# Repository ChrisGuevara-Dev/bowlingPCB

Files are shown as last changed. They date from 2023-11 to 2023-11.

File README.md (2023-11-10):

# Bowling PCB
This project focused on creating a printed circuit board (PCB) for the precise control of a bowling machine, utilizing the KiCAD design platform and the ESP32 microcontroller. The compact and robust design aimed to enhance the accuracy and reliability of ball launches, providing a comprehensive solution compatible with KiCAD standards.

## Schematic
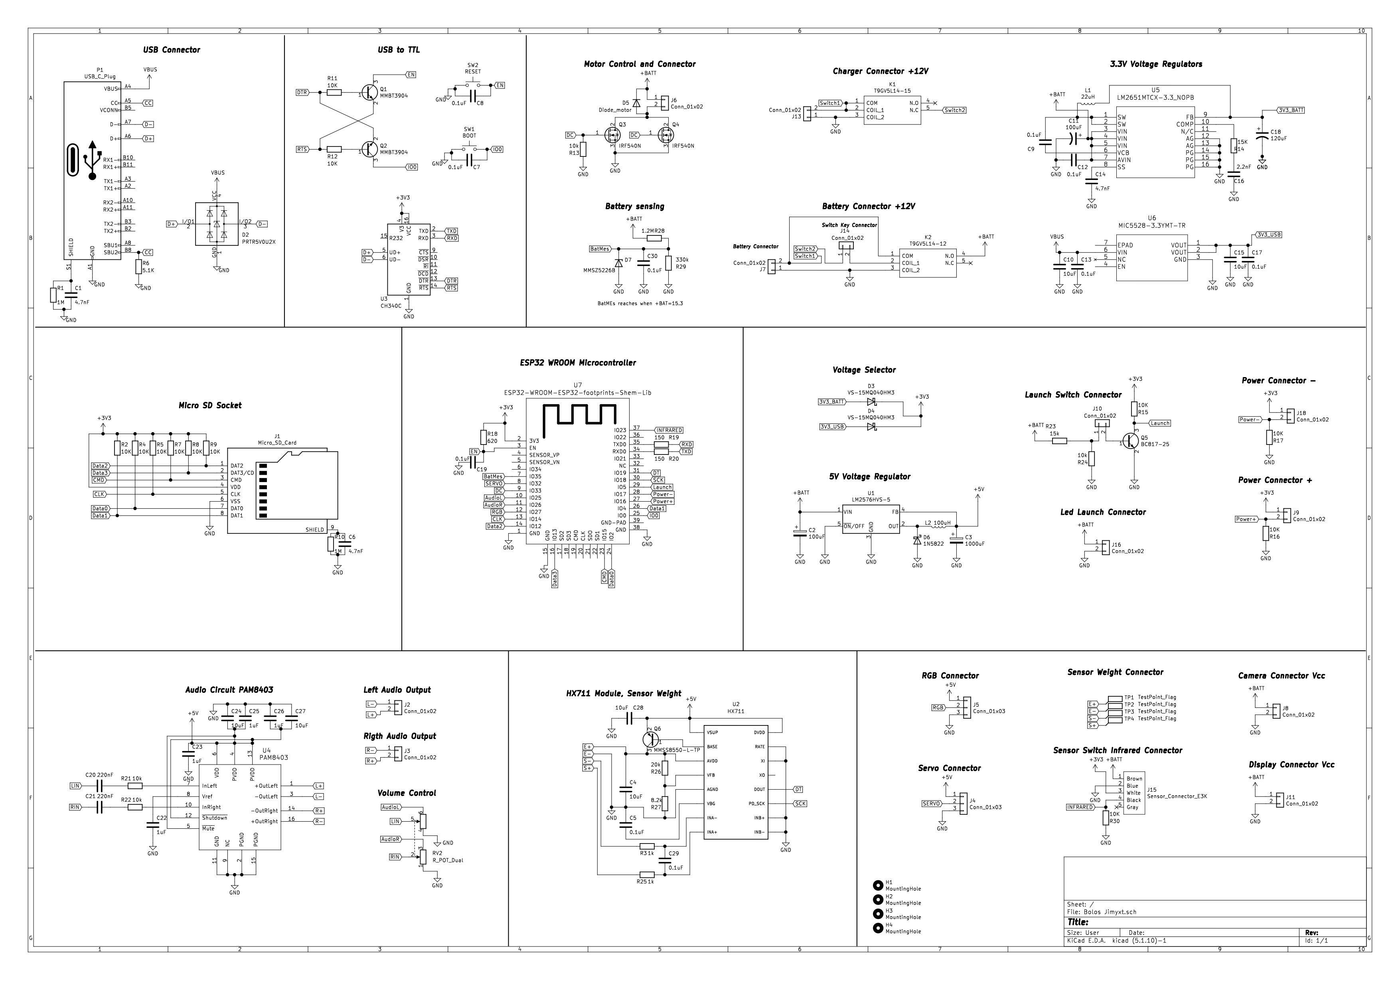
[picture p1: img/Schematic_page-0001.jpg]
Schematic


## 3D Model & Footprint
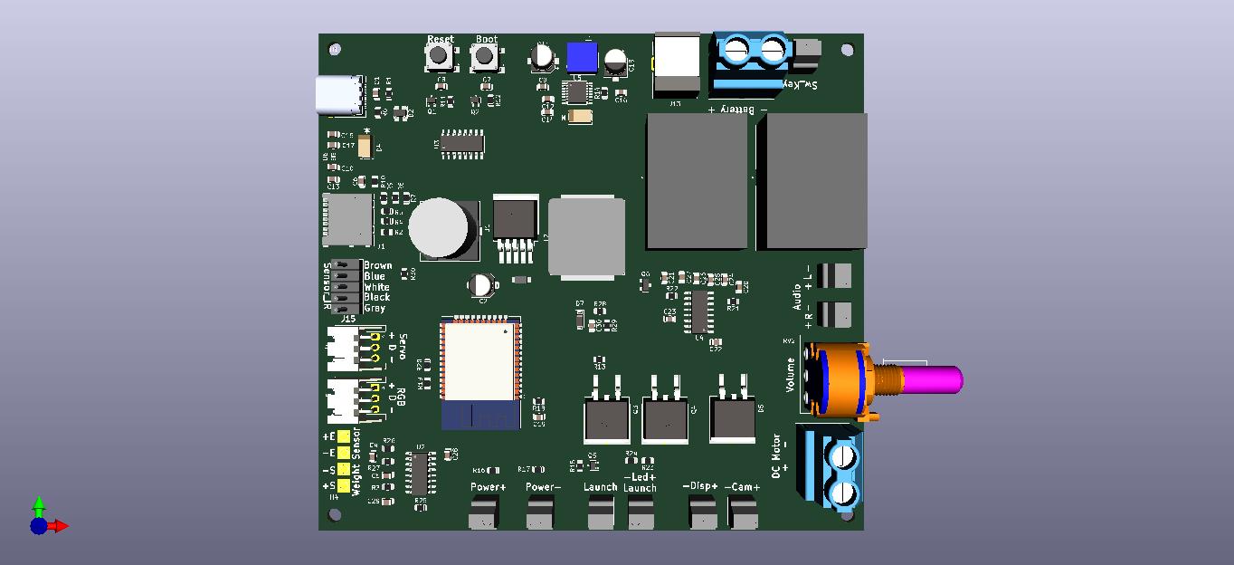
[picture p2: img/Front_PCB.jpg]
3D Model 1

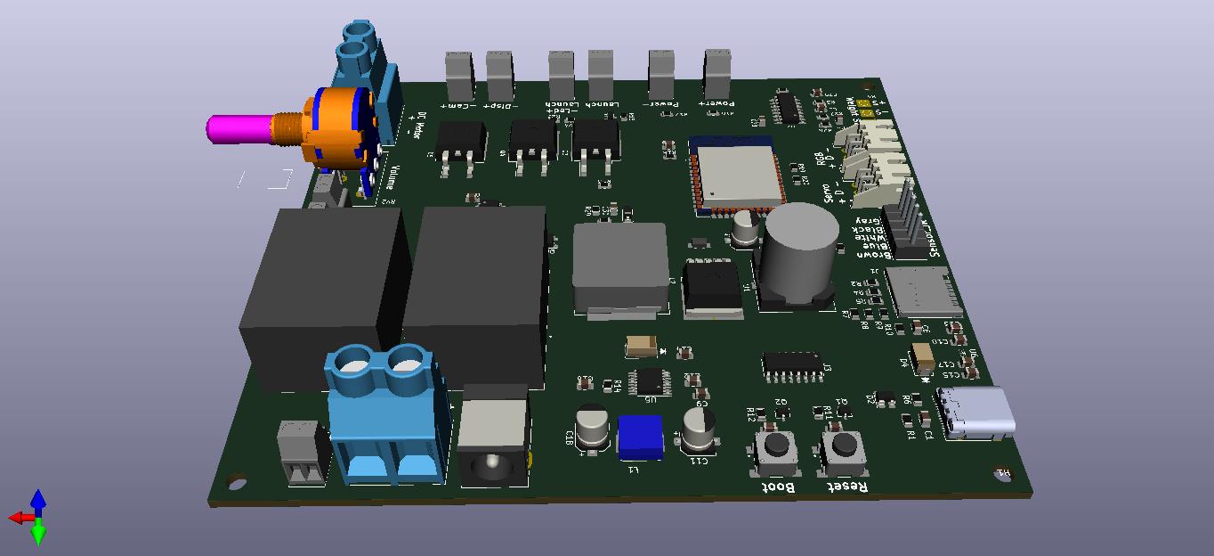
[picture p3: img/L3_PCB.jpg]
3D Model 2

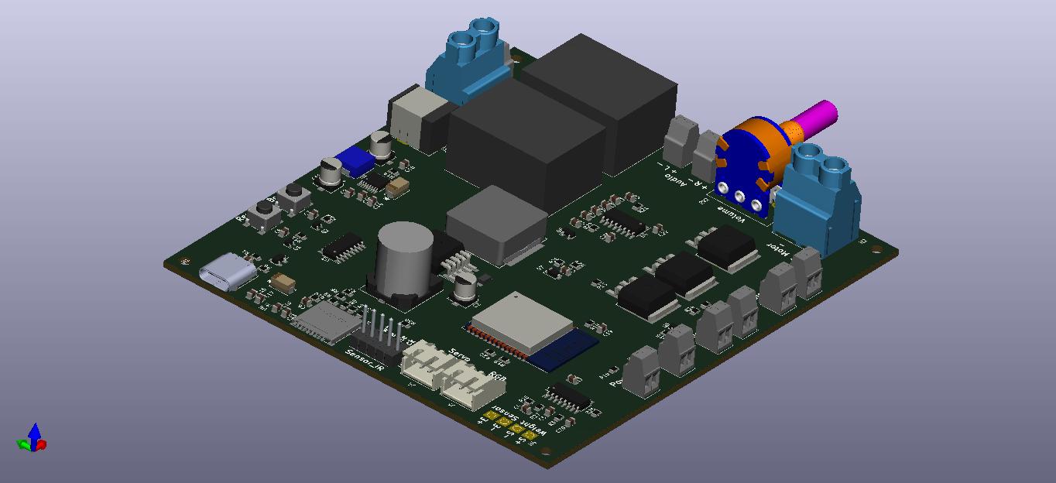
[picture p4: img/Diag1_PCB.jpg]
3D Model 3

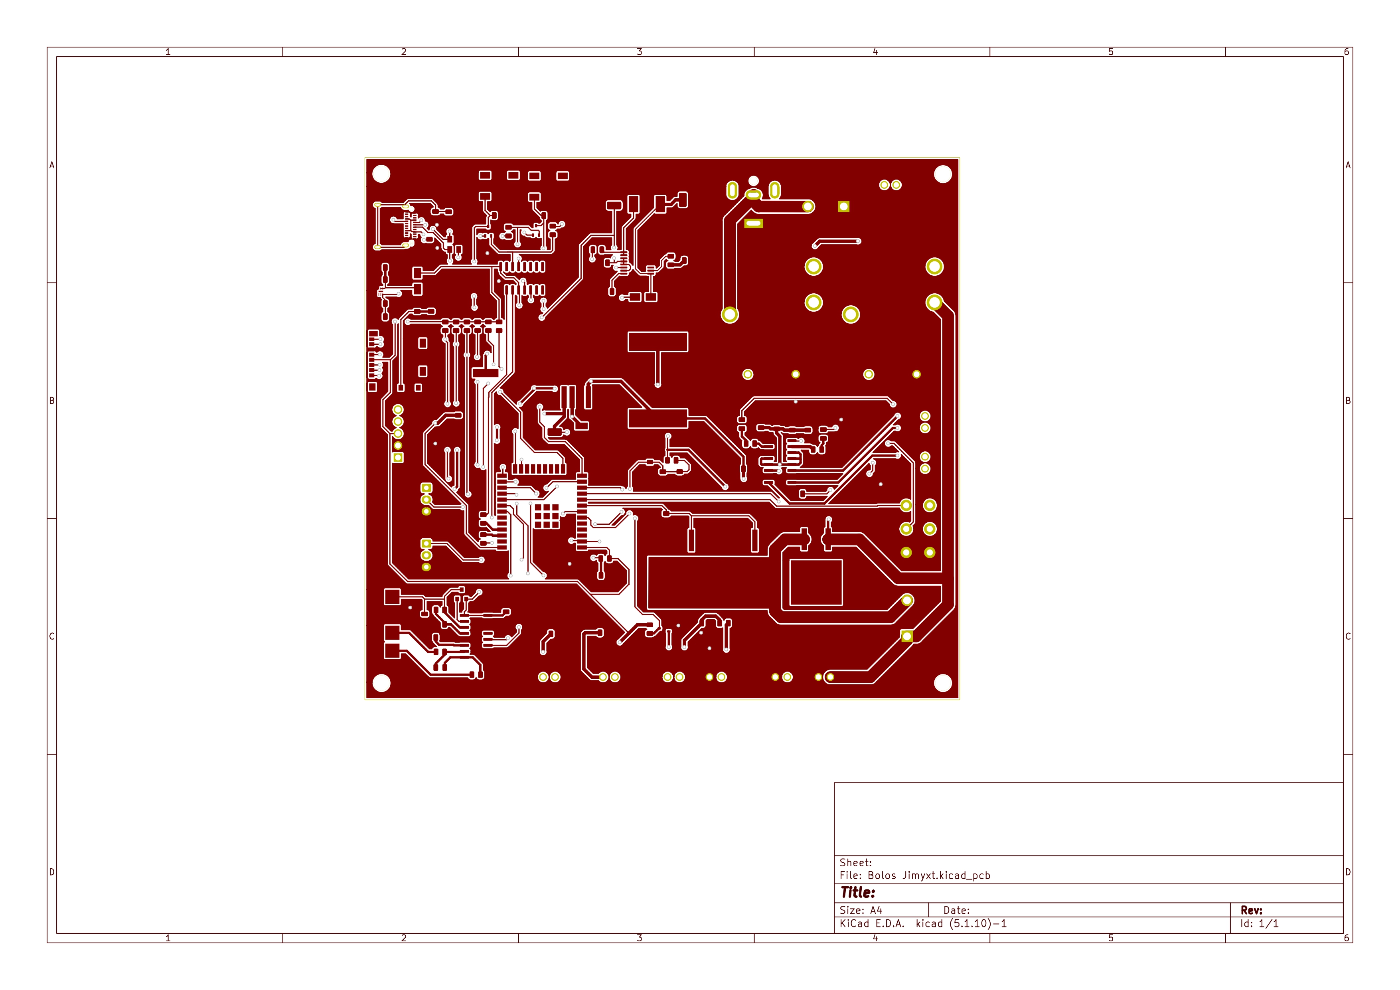
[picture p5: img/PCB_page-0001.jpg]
Footprint


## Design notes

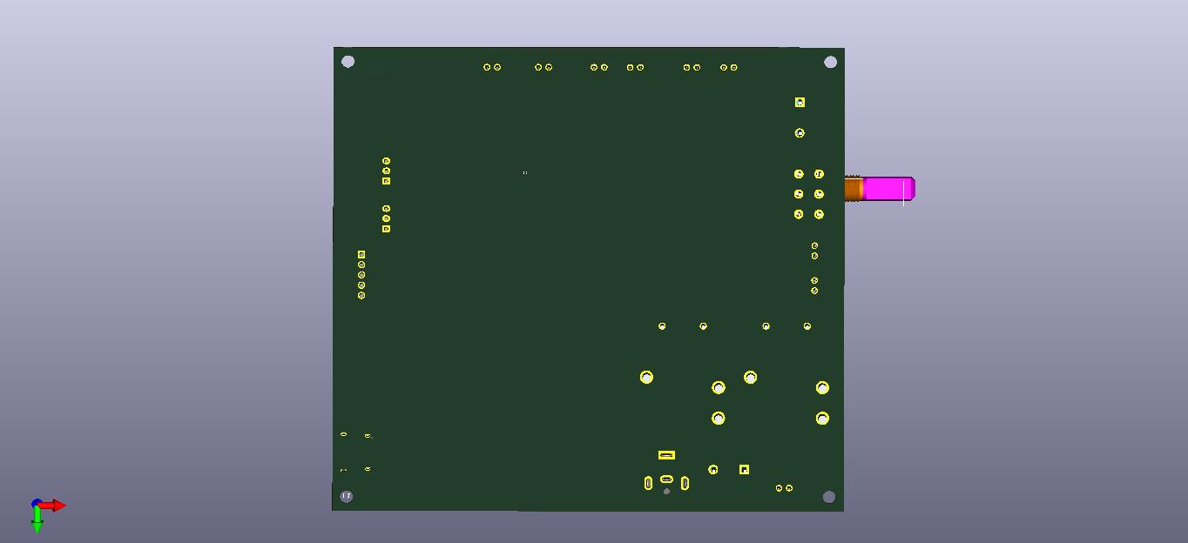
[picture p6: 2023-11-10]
img/Back_PCB.jpg

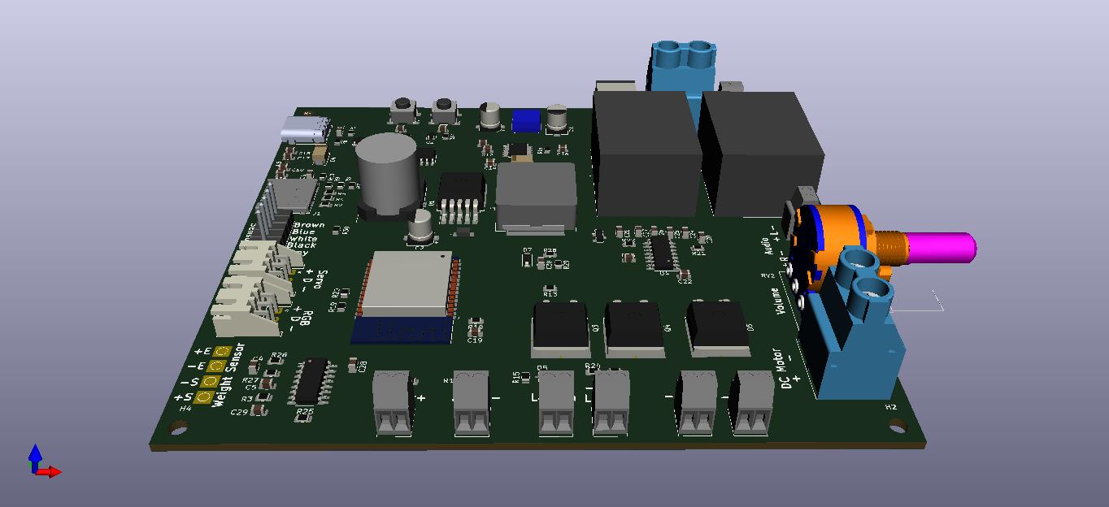
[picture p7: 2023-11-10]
img/L1_PCB.jpg

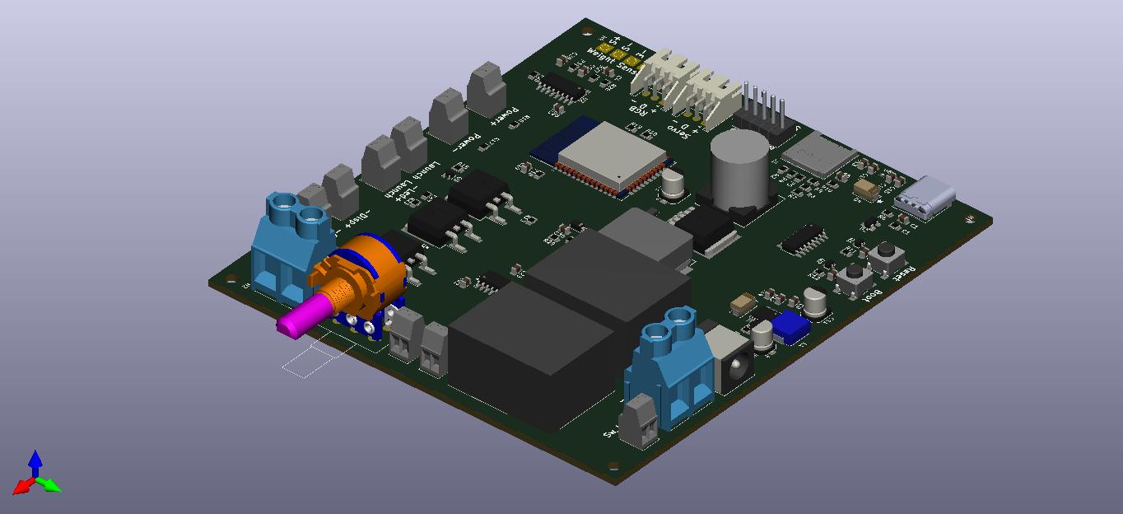
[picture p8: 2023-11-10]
img/Diag3_PCB.jpg

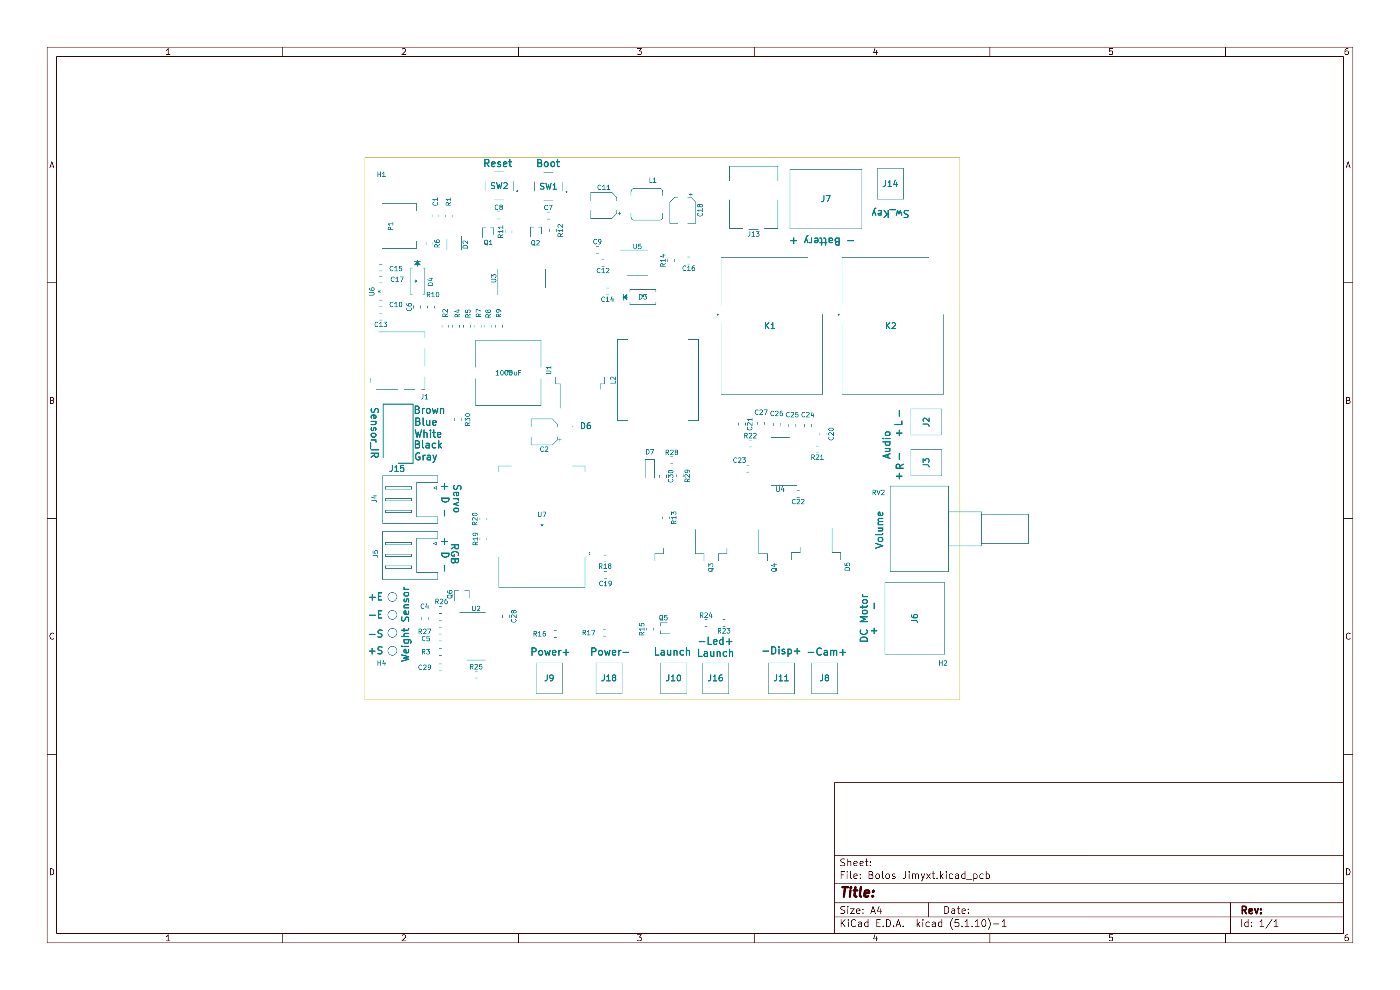
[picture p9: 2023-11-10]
img/PCB_page-0005.jpg

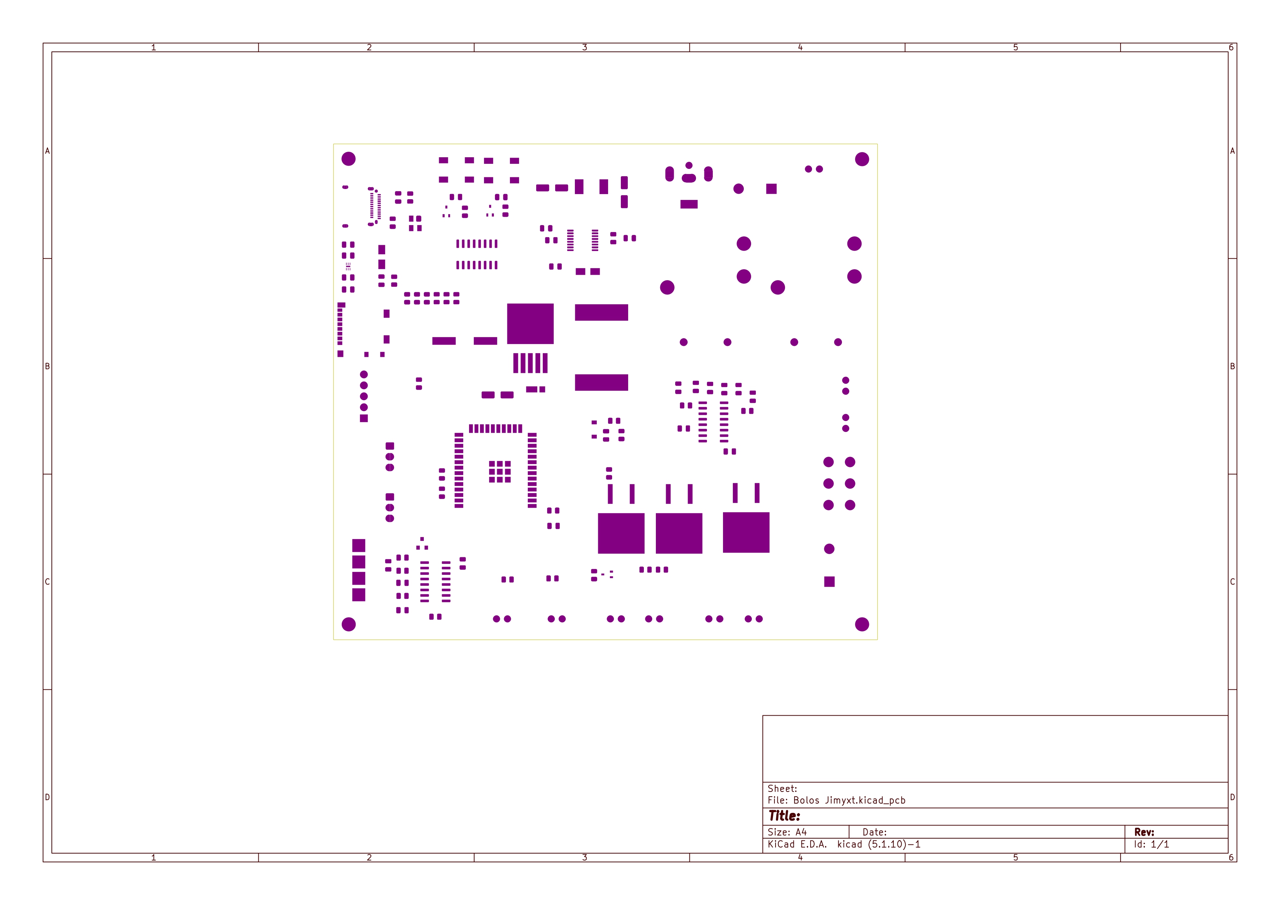
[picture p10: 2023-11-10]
img/PCB_page-0007.jpg

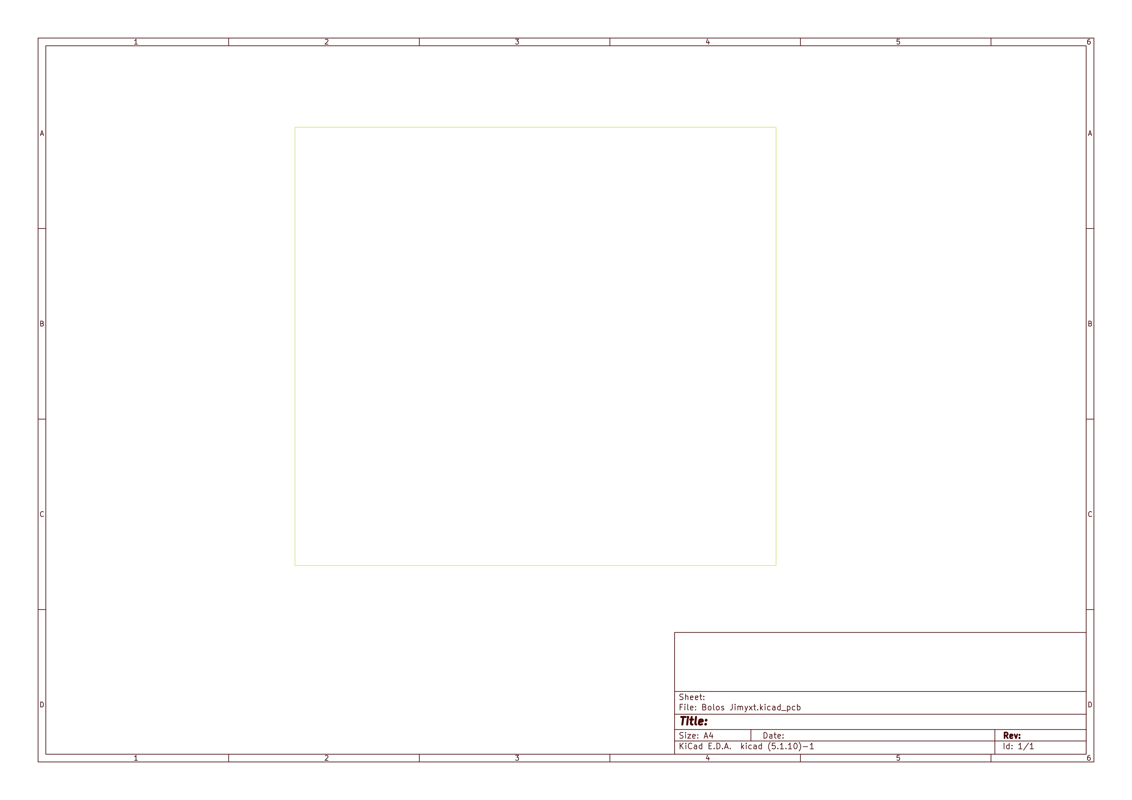
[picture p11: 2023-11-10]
img/PCB_page-0009.jpg

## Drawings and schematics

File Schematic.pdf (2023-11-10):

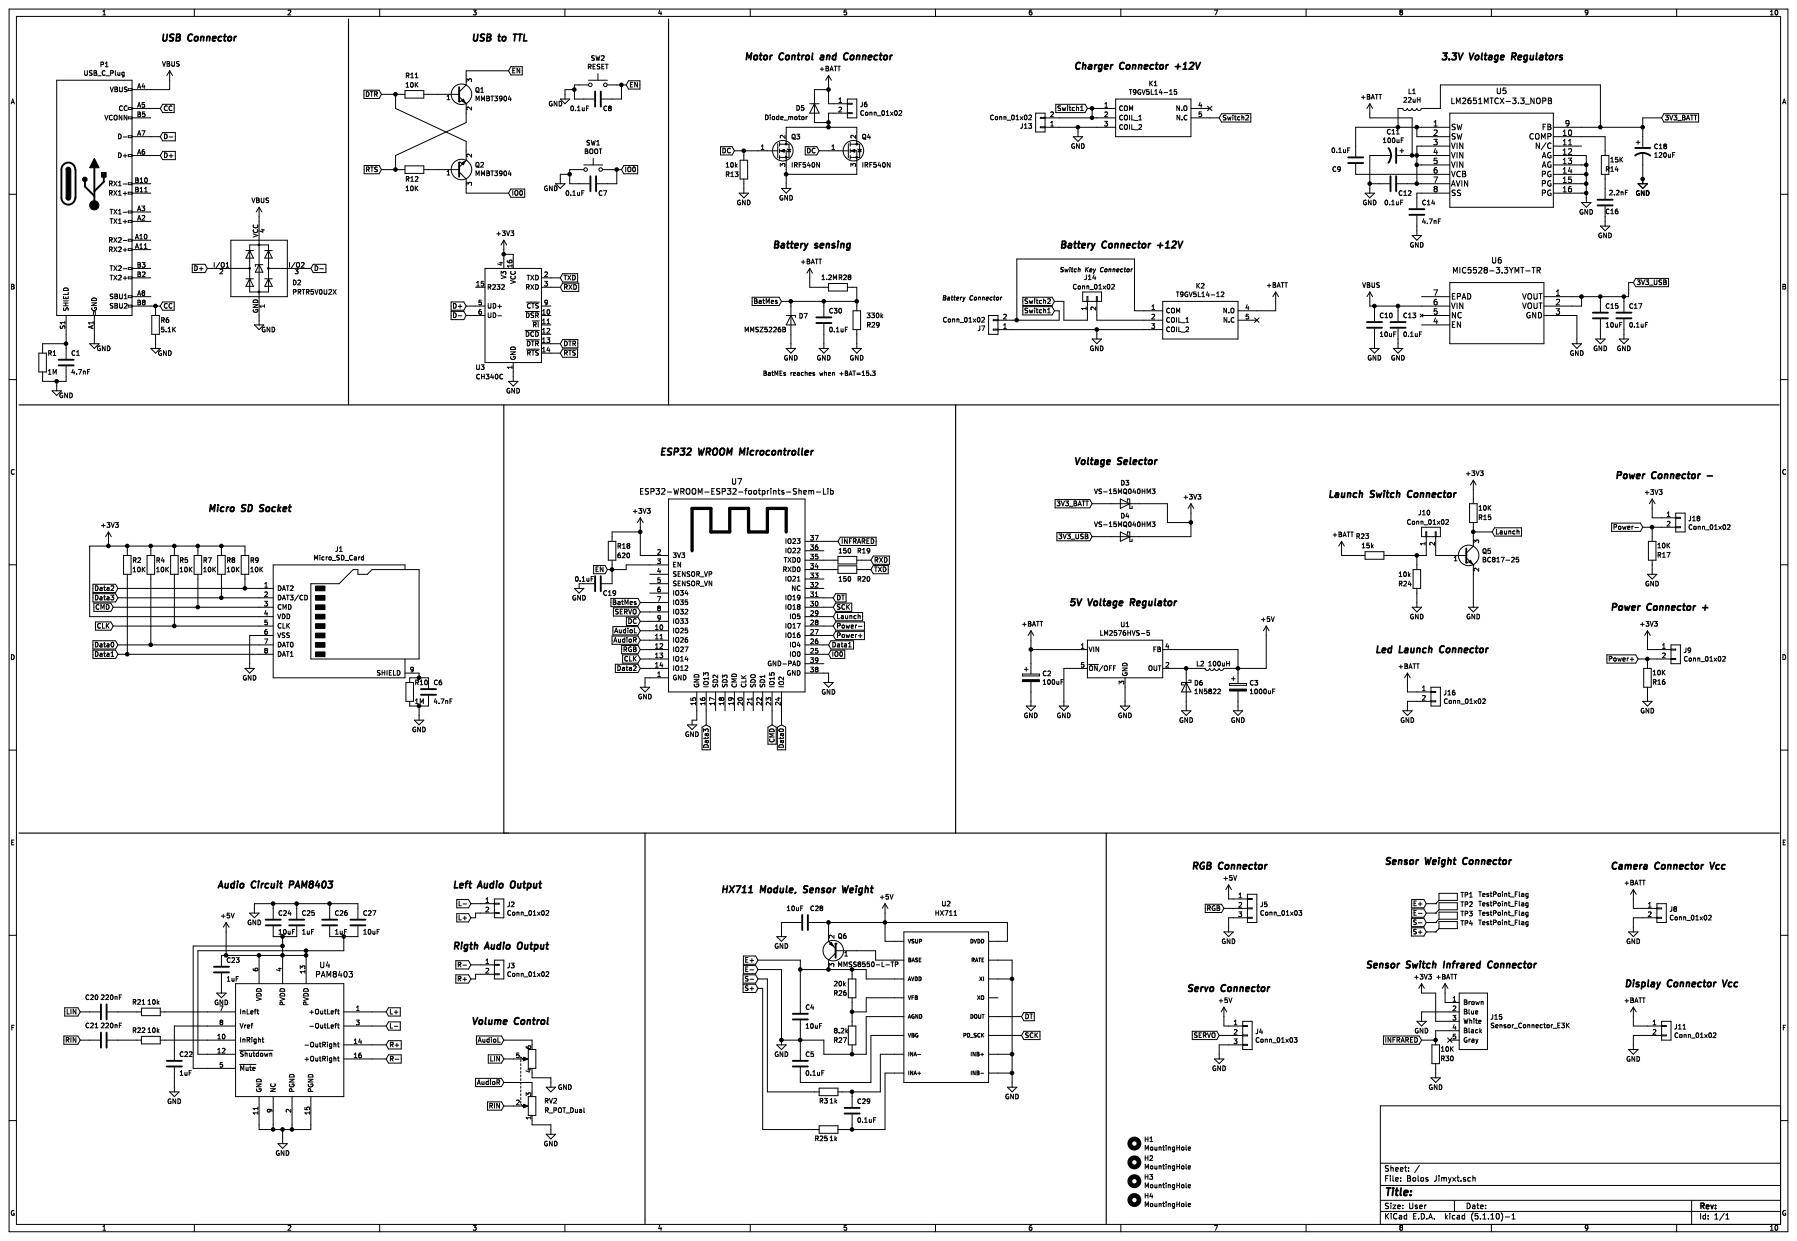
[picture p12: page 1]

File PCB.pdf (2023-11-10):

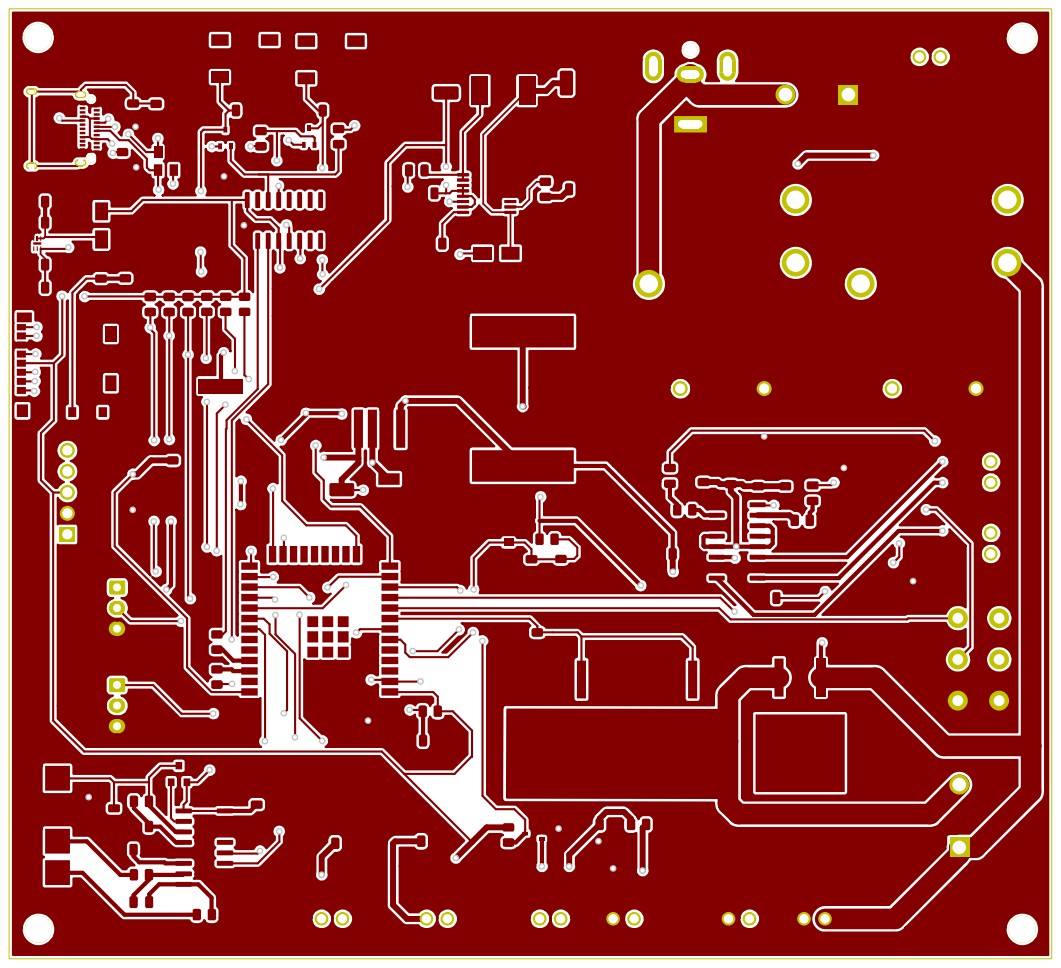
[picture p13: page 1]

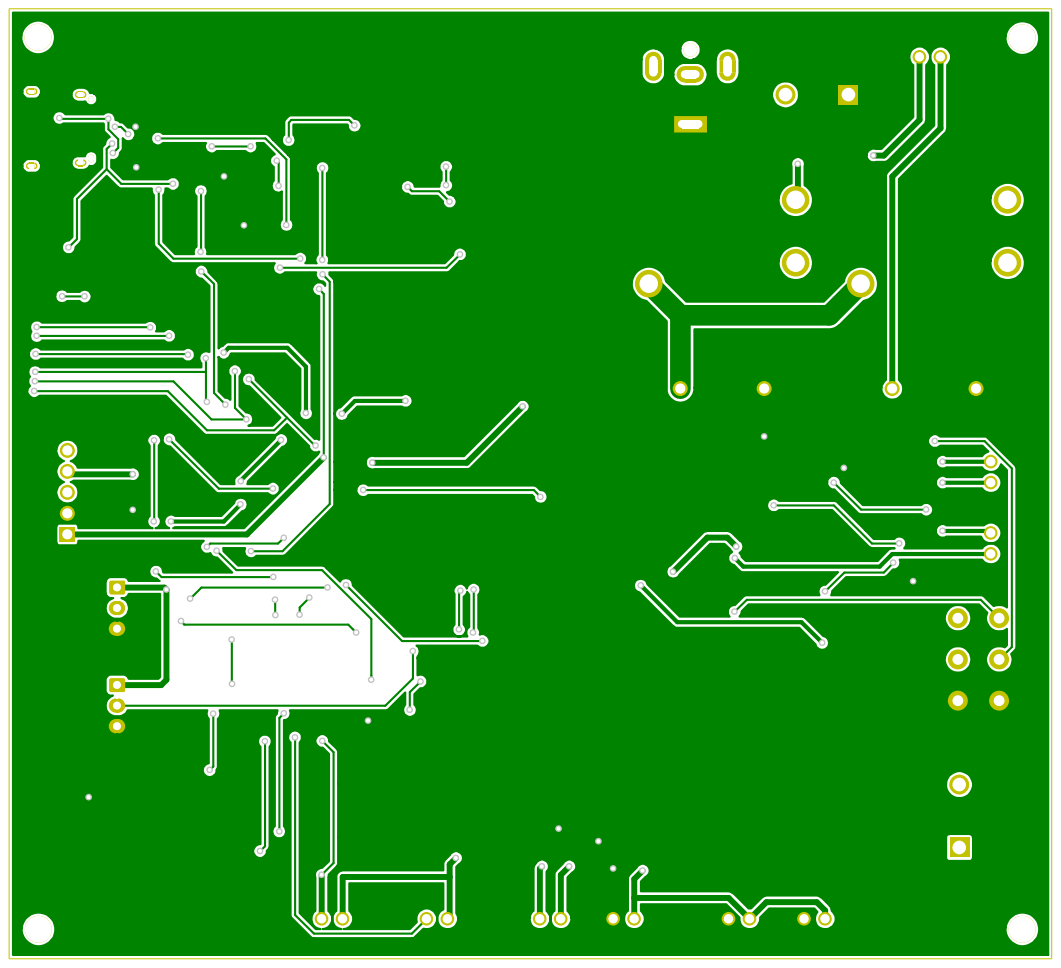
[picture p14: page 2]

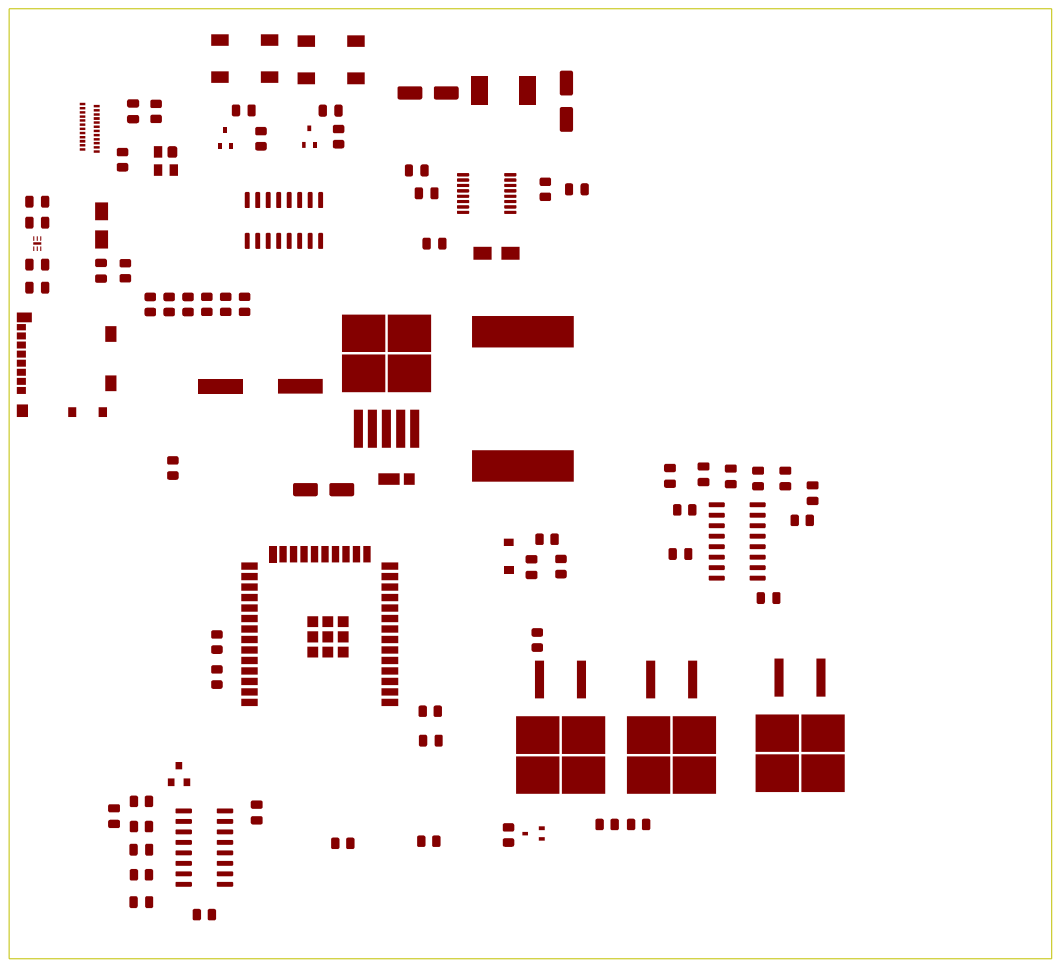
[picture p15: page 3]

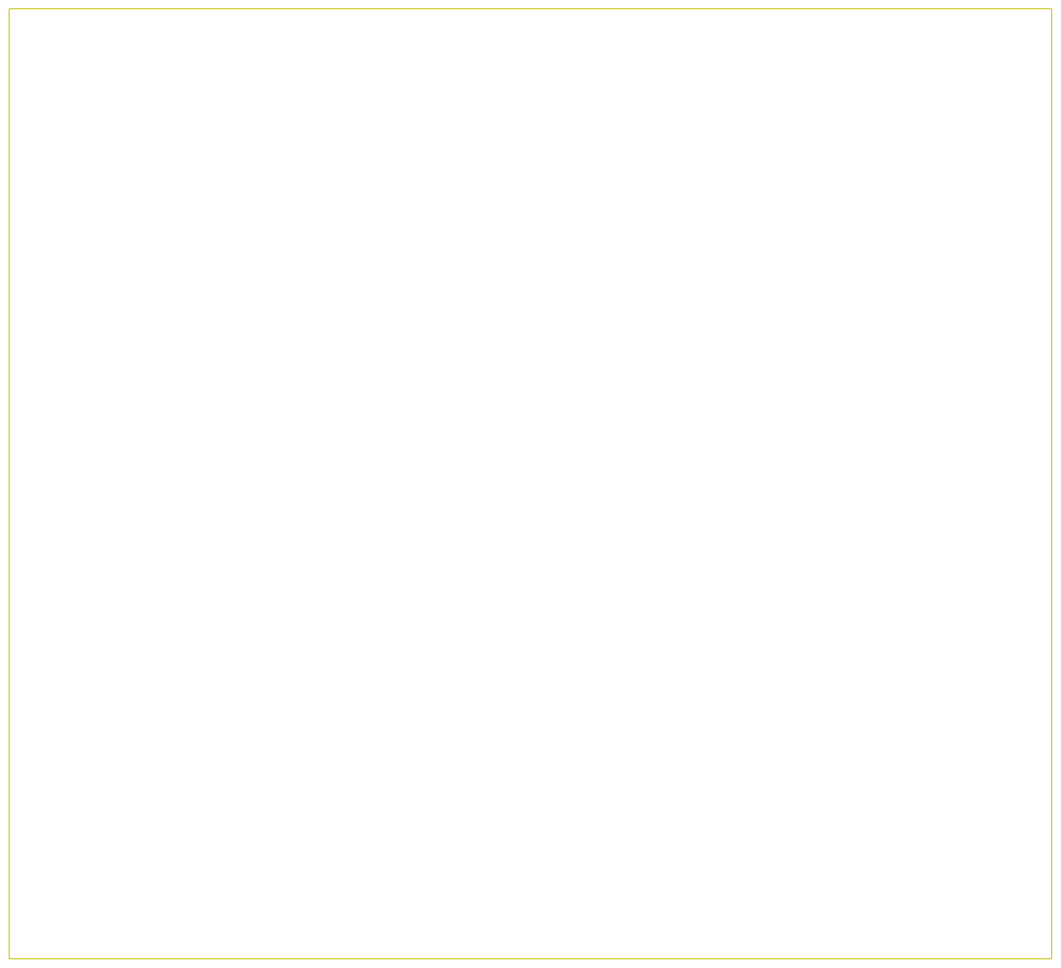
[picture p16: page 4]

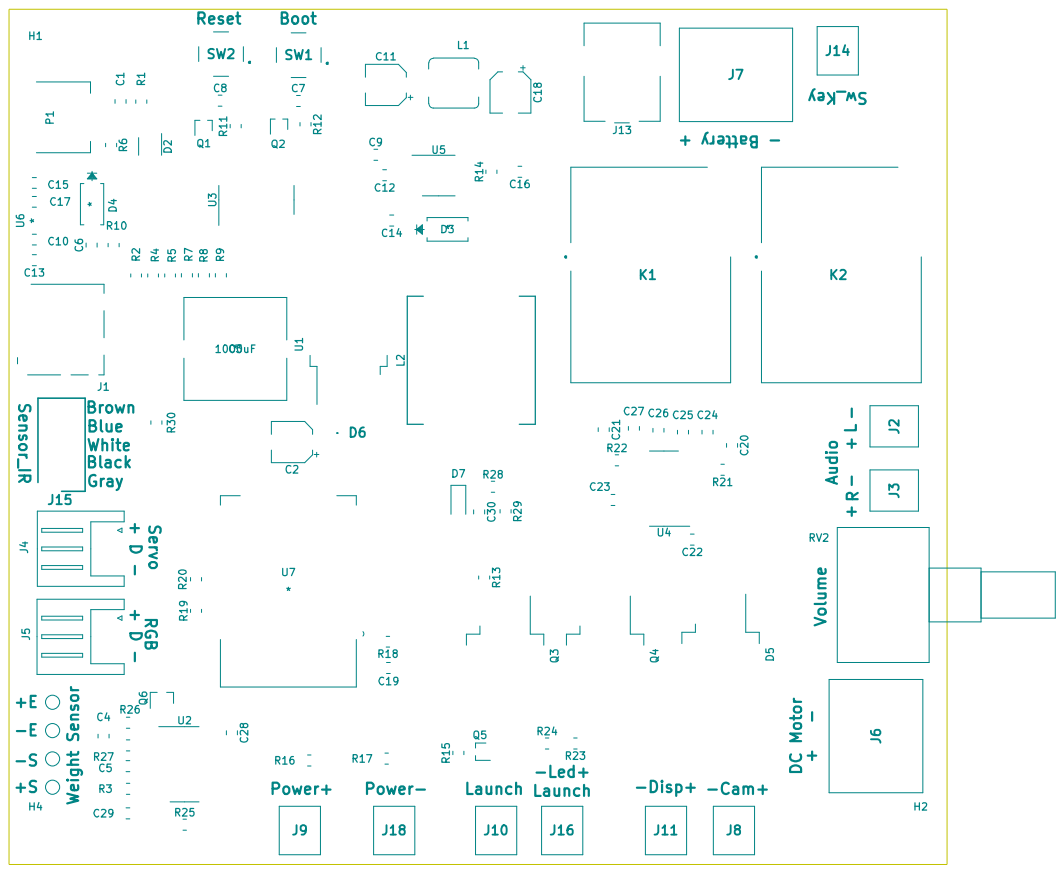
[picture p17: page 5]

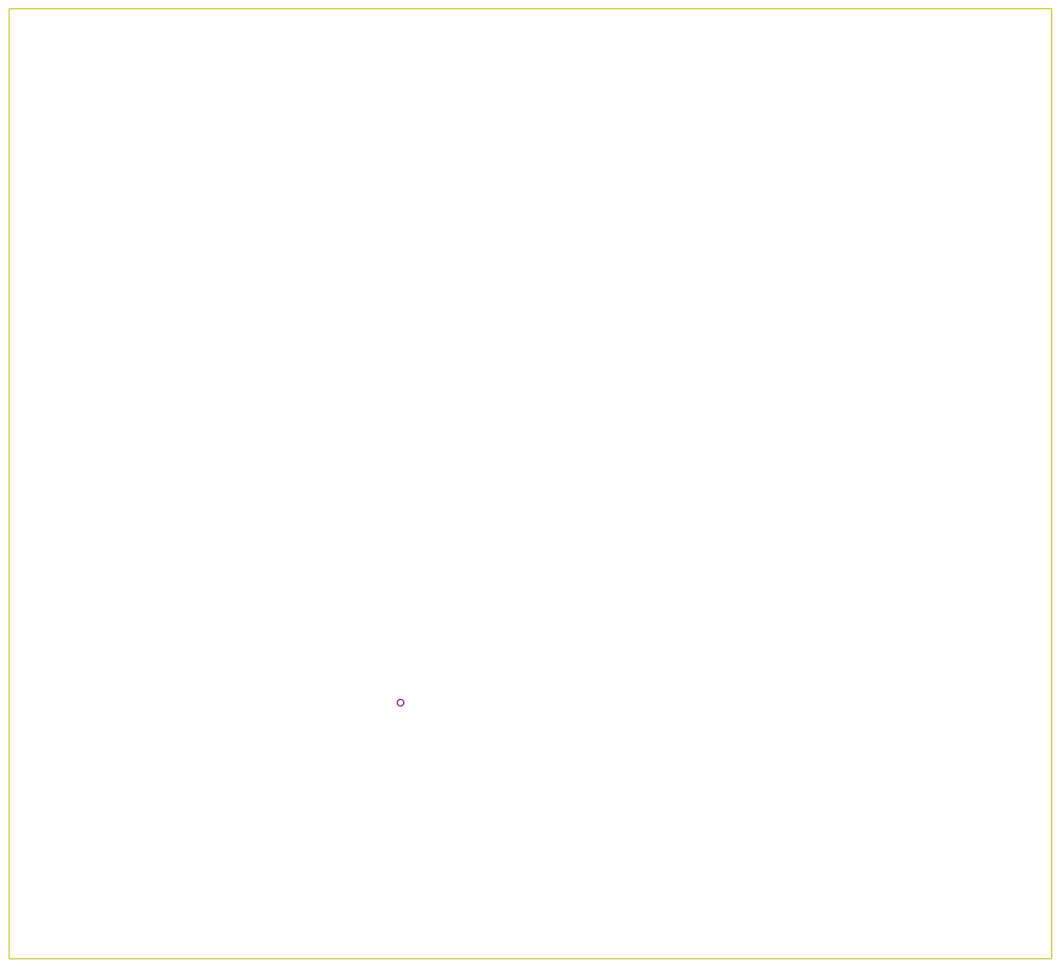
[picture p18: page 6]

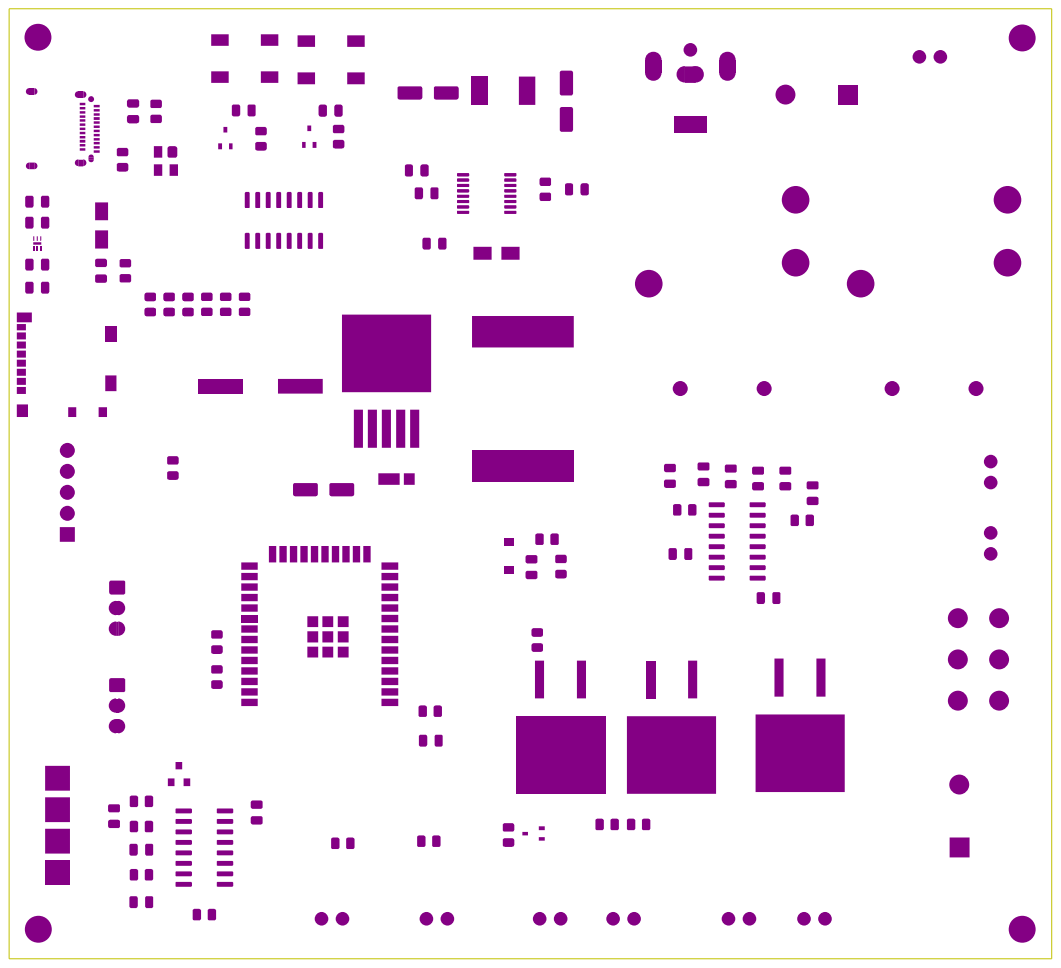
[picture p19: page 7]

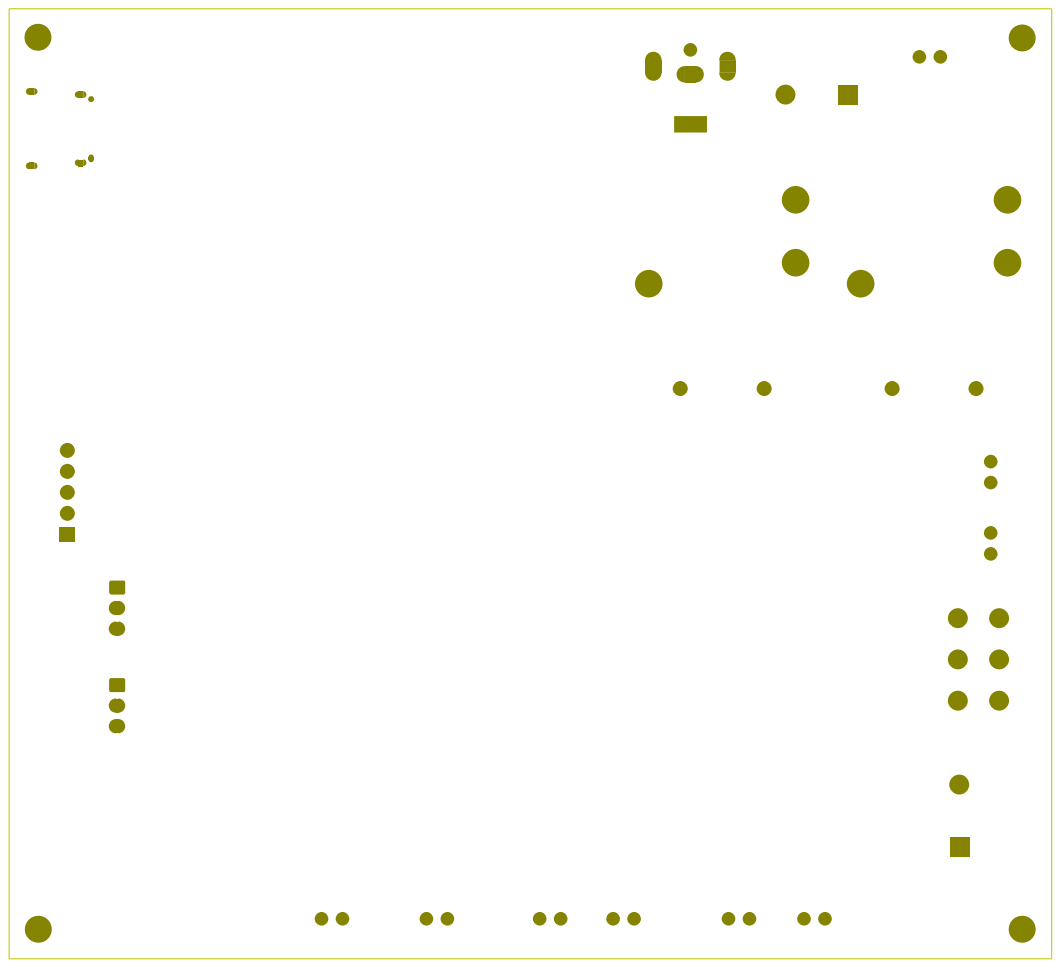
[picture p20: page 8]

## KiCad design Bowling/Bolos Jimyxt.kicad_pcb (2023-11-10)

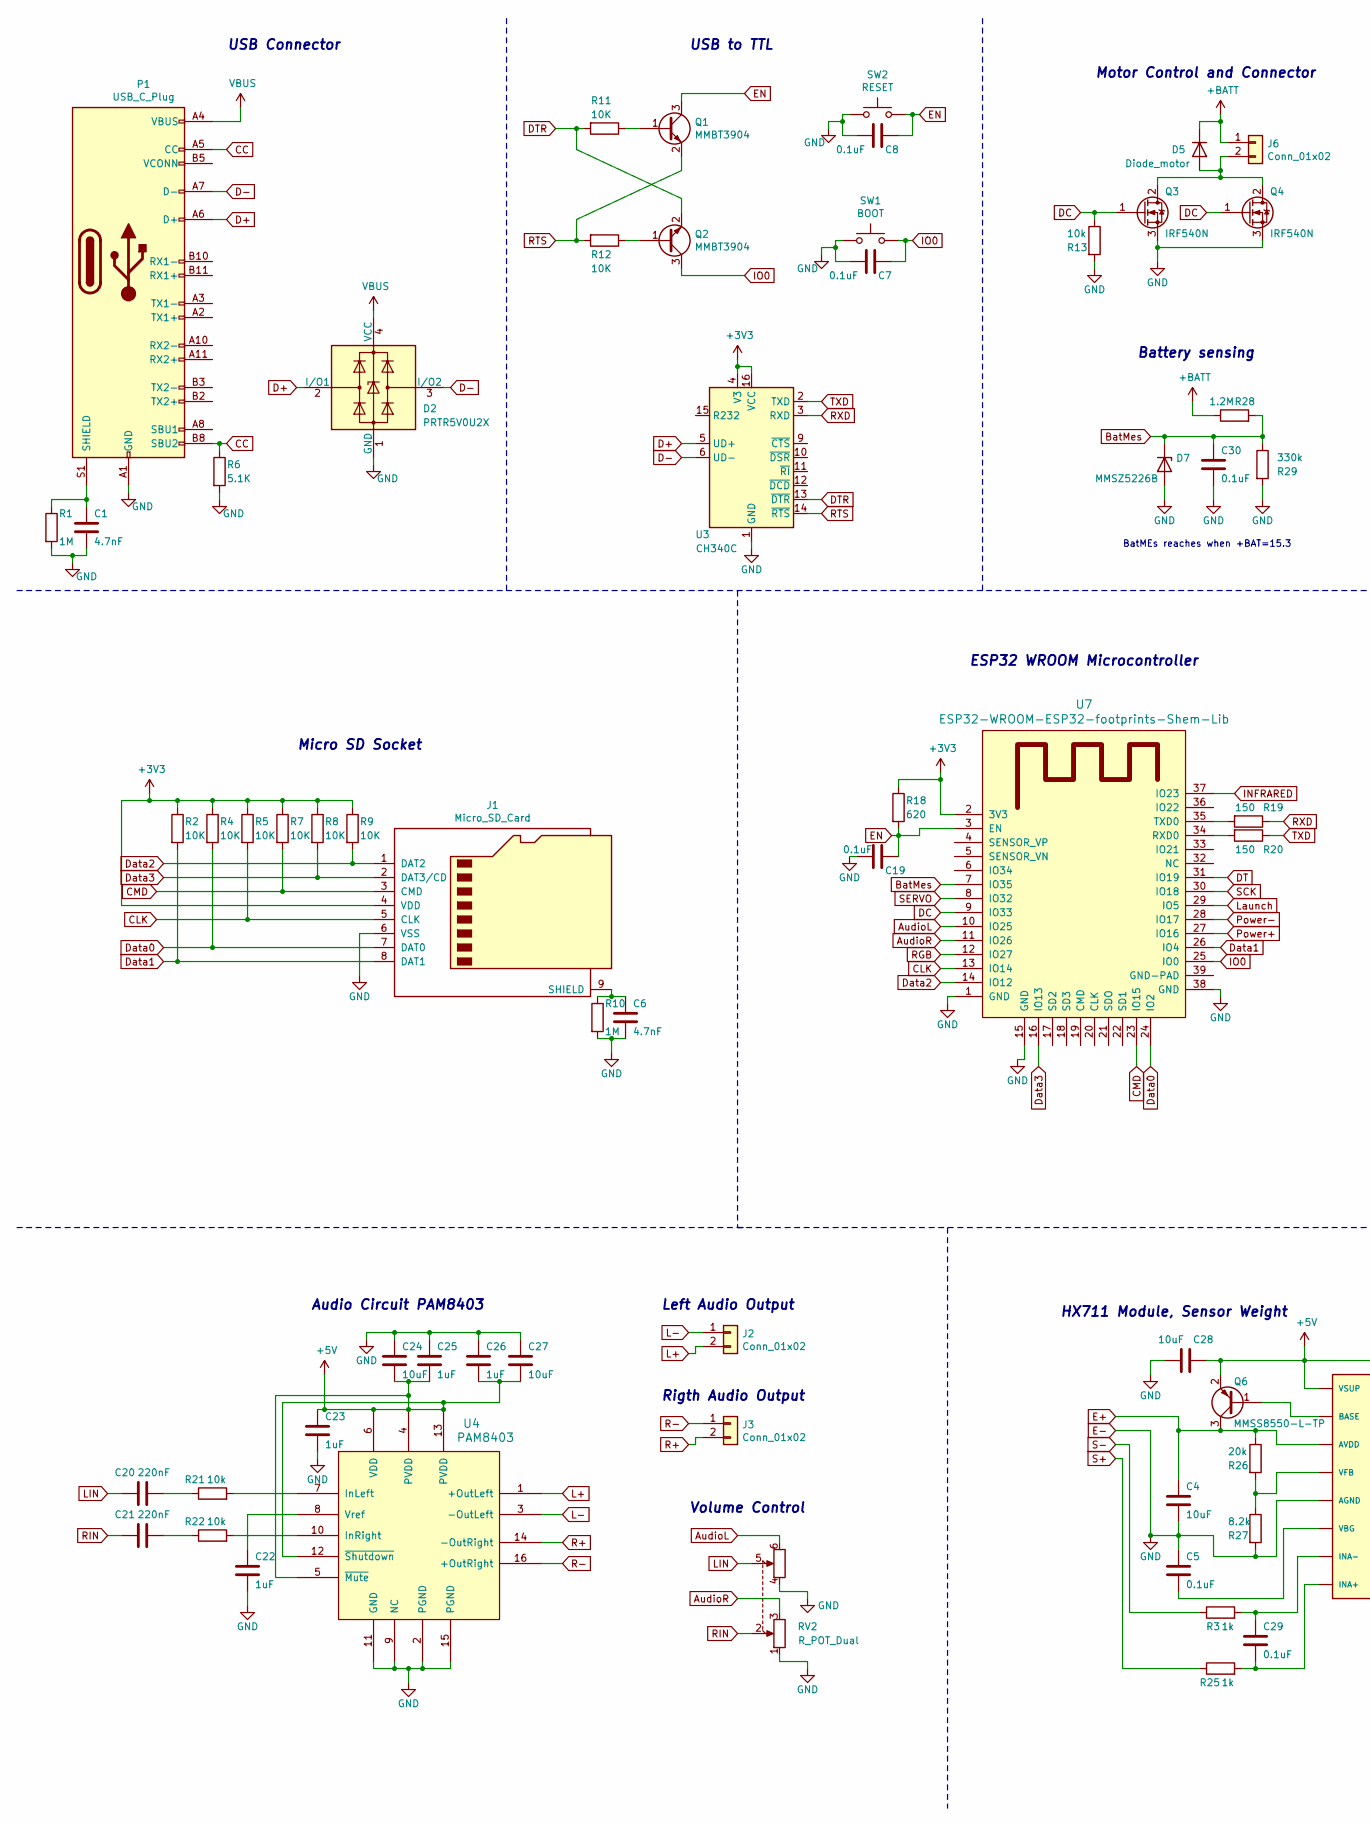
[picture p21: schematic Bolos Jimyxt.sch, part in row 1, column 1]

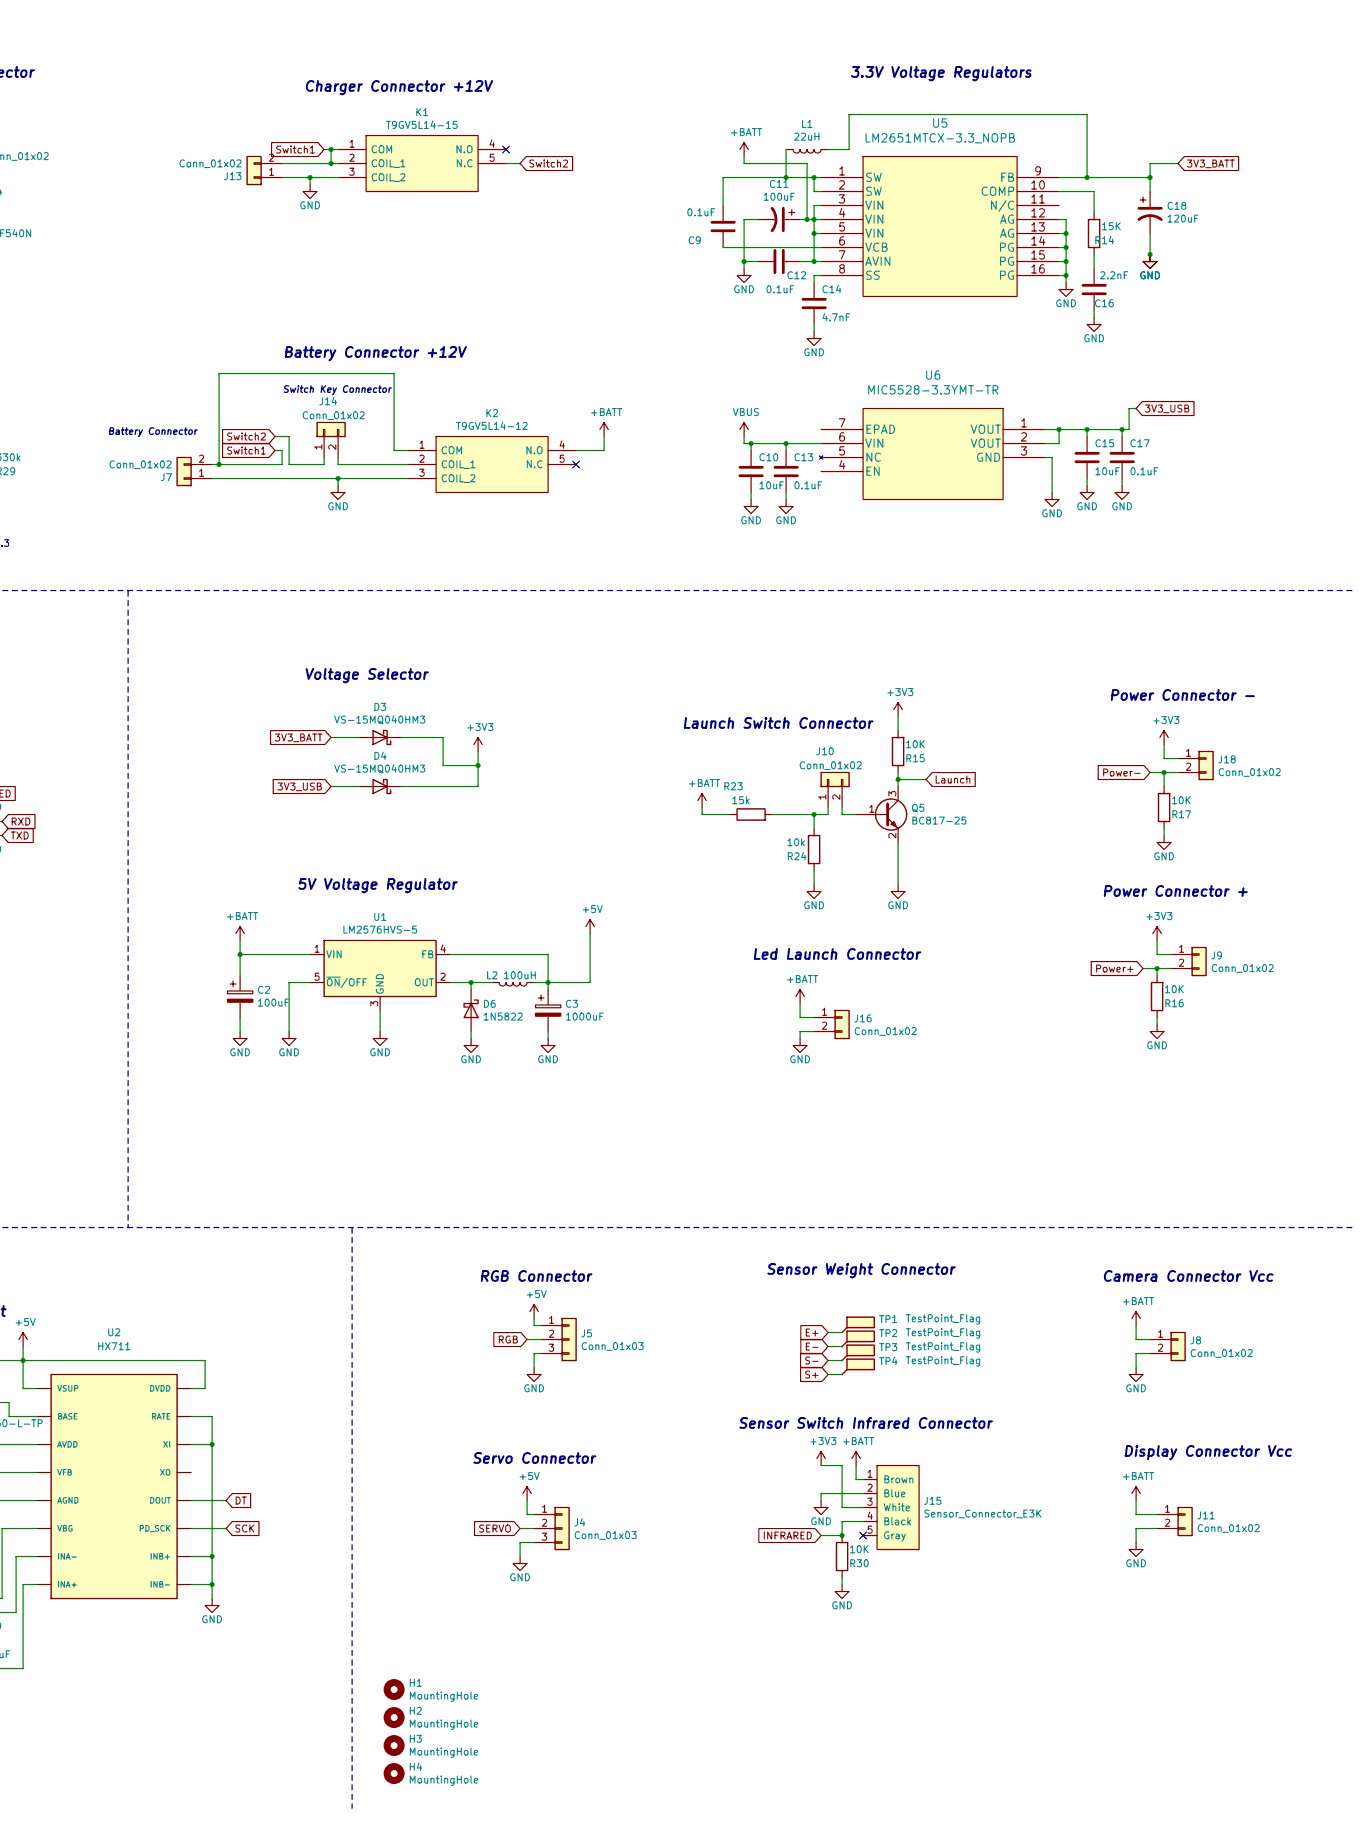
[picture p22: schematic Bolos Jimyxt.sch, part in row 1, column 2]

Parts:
C1, C6, C14: 4.7nF; C_0805_2012Metric; MFG PN C0805C472J3GEC7210
C2, C11: 100uF; CP_Elec_5x5.8; MFG PN EEE-FK1C101SR
C3: 1000uF; UUG1A102MNQ1MS; MFG PN UUG1A102MNQ1MS
C4, C10, C15, C24, C27, C28: 10uF; C_0805_2012Metric; MFG PN C2012X5R1E106M125AB
C5, C7, C8, C9, C12, C13, C17, C19, C29, C30: 0.1uF; C_0805_2012Metric; MFG PN C0805C104J3RECAUTO7210
C16: 2.2nF; C_0805_2012Metric; MFG PN C0805C222K3GECTU
C18: 120uF; CP_Elec_5x5.8; MFG PN EEE-FK1A121SR
C20, C21: 220nF; C_0805_2012Metric; MFG PN C0805C224J3RACTU
C22, C23, C25, C26: 1uF; C_0805_2012Metric; MFG PN C0805C105M3REC7210
D2: PRTR5V0U2X; SOT-143; MFG PN PRTR5V0U2X,215
D3, D4: VS-15MQ040HM3; VS-15MQ040NPBF; MFG PN VS-15MQ040HM3/5AT
D5: Diode_motor; TO-263-2; MFG PN PSDB3060S1_T0_00001
D6: 1N5822; SS3040HE_R1_00001; MFG PN SS3040HE_R1_00001
D7: MMSZ5226B; D_SOD-123; MFG PN MMSZ5226B_R1_00001
H1, H2, H3, H4: MountingHole; MountingHole_3.2mm_M3; MFG PN DNP
J1: Micro_SD_Card; microSD_HC_Molex_104031-0811; MFG PN 104031-0811
J2, J3, J8, J9, J10, J11, J14, J16, J18: Conn_01x02; 397730002; MFG PN 39773-0002
J4, J5: Conn_01x03; JST_XH_S3B-XH-A_1x03_P2.50mm_Horizontal; MFG PN S3B-XH-A(LF)(SN)
J6, J7: Conn_01x02; TB00576202BE; MFG PN TB005-762-02BE
J13: Conn_01x02; BarrelJack_CUI_PJ-063AH_Horizontal; MFG PN PJ-063AH
J15: Sensor_Connector_E3K; 171856-0105; MFG PN 171856-0105
K1: T9GV5L14-15; T9GV5L145; Manufacturer_Part_Number T9GV5L14-5; Mouser Part Number 655-T9GV5L14-5
K2: T9GV5L14-12; T9GV5L145; Manufacturer_Part_Number T9GV5L14-5; Mouser Part Number 655-T9GV5L14-5
L1: 22uH; L_Sumida_CDMC6D28_7.25x6.5mm; MFG PN ASPI-0630LR-220M-T15
L2: 100uH; L_Vishay_IHLP-6767; MFG PN IHLP6767GZER101M11
P1: USB_C_Plug; USB_C_Receptacle_Amphenol_12401610E4-2A; MFG PN 12401610E4#2A
Q1, Q2: MMBT3904; SOT-323_SC-70; MFG PN MMBT3904W_R1_00001
Q3, Q4: IRF540N; TO-263-2; MFG PN IRF540SPBF
Q5: BC817-25; SOT-323_SC-70; MFG PN BC817-25_R1_00001
Q6: MMSS8550-L-TP; SOT-23; MFG PN MMSS8550-L-TP
R1, R10: 1M; R_0805_2012Metric; MFG PN CMP0805-FX-1004ELF
R2, R4, R5, R7, R8, R9, R11, R12, R15, R16, R17, R30: 10K; R_0805_2012Metric; MFG PN ERJ-UP6J103V
R3, R25: 1k; R_0805_2012Metric; MFG PN ERJ-P06F1001V
R6: 5.1K; R_0805_2012Metric; MFG PN ERJ-T06J512V
R13, R21, R22, R24: 10k; R_0805_2012Metric; MFG PN ERJ-UP6J103V
R14: 15K; R_0805_2012Metric; MFG PN ERJ-P06F1502V
R18: 620; R_0805_2012Metric; MFG PN ERJ-P06J621V
R19, R20: 150; R_0805_2012Metric; MFG PN ERJ-P06F1500V
R23: 15k; R_0805_2012Metric; MFG PN ERJ-P06F1502V
R26: 20k; R_0805_2012Metric; MFG PN ERJ-P06J203V
R27: 8.2k; R_0805_2012Metric; MFG PN ERJ-P06F8201V
R28: 1.2M; R_0805_2012Metric; MFG PN ERJ-P06J125V
R29: 330k; R_0805_2012Metric; MFG PN ERJ-T06J334V
RV2: R_POT_Dual; Potentiometer_Alps_RK163_Dual_Horizontal; MFG PN RK16312A0BKH
SW1: BOOT; LL3301FF065QJ; MFG PN LL3301AF065QJ
SW2: RESET; LL3301FF065QJ; MFG PN LL3301AF065QJ
TP1, TP2, TP3, TP4: TestPoint_Flag; TestPoint_Pad_D1.5mm; MFG PN DNP
U1: LM2576HVS-5; TO-263-5_TabPin3; MFG PN LM2576HVS-5.0/NOPB
U2: HX711; SOP-16_3.9x9.9mm_P1.27mm; MFG PN HX711
U3: CH340C; SOIC-16_3.9x9.9mm_P1.27mm; MFG PN CH340C
U4: PAM8403; SOIC-16_3.9x9.9mm_P1.27mm; MFG PN PAM8403DR-H
U5: LM2651MTCX-3.3_NOPB; TSSOP-16_4.4x5mm_P0.65mm; MFG PN LM2651MTCX-3.3/NOPB
U6: MIC5528-3.3YMT-TR; MFG PN MIC5528-3.3YMT-TR
U7: ESP32-WROOM-ESP32-footprints-Shem-Lib; ESP32-WROOM-32 8MB; MFG PN ESP32-WROOM-32

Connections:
3V3_BATT: C18.1, D3.2 (A), L1.1, U5.9 (FB)
3V3_USB: C15.1, C17.1, D4.2 (A), U6.1 (VOUT), U6.2 (VOUT)
+3V3: D3.1 (K), D4.1 (K), J1.4 (VDD), J9.1, J15.3 (White), J18.1, R2.1, R4.1, R5.1, R7.1, R8.1, R9.1, R15.2, R18.1, U3.4 (V3), U3.16 (VCC), U7.2 (3V3)
+5V: C3.1, C23.1, C24.2, C25.2, C26.2, C27.2, C28.1, J4.1, J5.1, L2.1, Q6.2 (E), U1.4 (FB), U2.1 (VSUP), U2.16 (DVDD), U4.4 (PVDD), U4.5 (~Mute), U4.6 (VDD), U4.12 (~Shutdown), U4.13 (PVDD)
+BATT: C2.1, C11.1, C12.1, D5.1 (K), J6.1, J8.1, J11.1, J15.1 (Brown), J16.1, K2.4 (N.O), R23.1, R28.1, U1.1 (VIN), U5.3 (VIN), U5.4 (VIN), U5.5 (VIN), U5.7 (AVIN)
AudioL: RV2.6, U7.10 (IO25)
AudioR: RV2.3, U7.11 (IO26)
BatMes: C30.1, D7.1 (K), R28.2, R29.1, U7.7 (IO35)
CC: P1.A5 (CC), P1.B8 (SBU2), R6.1
CLK: J1.5 (CLK), R5.2, U7.13 (IO14)
CMD: J1.3 (CMD), R7.2, U7.23 (IO15)
D+: D2.2 (I/O1), P1.A6 (D+), U3.5 (UD+)
D-: D2.3 (I/O2), P1.A7 (D-), U3.6 (UD-)
DC: Q3.1 (G), Q4.1 (G), R13.1, U7.9 (IO33)
DT: U2.12 (DOUT), U7.31 (IO19)
DTR: Q2.2 (E), R11.2, U3.13 (~DTR)
Data0: J1.7 (DAT0), R4.2, U7.24 (IO2)
Data1: J1.8 (DAT1), R2.2, U7.26 (IO4)
Data2: J1.1 (DAT2), R9.2, U7.14 (IO12)
Data3: J1.2 (DAT3/CD), R8.2, U7.16 (IO13)
E+: C4.1, Q6.3 (C), R26.1, TP1.1, U2.3 (AVDD)
E-: C1.2, C2.2, C3.2, C4.2, C5.1, C6.2, C7.2, C8.2, C10.2, C11.2, C12.2, C13.2, C14.2, C15.2, C16.1, C17.2, C18.2, C19.2, C22.2, C23.2, C24.1, C25.1, C26.1, C27.1, C28.2, C30.2, D2.1 (GND), D6.2 (A), D7.2 (A), J1.6 (VSS), J4.3, J5.3, J7.1, J8.2, J11.2, J13.1, J15.2 (Blue), J16.2, K1.3 (COIL_2), K2.3 (COIL_2), P1.A1 (GND), P1.A12 (GND), P1.B1 (GND), P1.B12 (GND), Q3.3 (S), Q4.3 (S), Q5.2 (E), R1.2, R6.2, R10.2, R13.2, R16.1, R17.1, R24.2, R27.2, R29.2, R30.1, RV2.1, RV2.4, SW1.1, SW2.1, TP2.1, U1.3 (GND), U1.5 (~ON~/OFF), U2.5 (AGND), U2.9 (INB-), U2.10 (INB+), U2.14 (XI), U2.15 (RATE), U3.1 (GND), U4.2 (PGND), U4.9 (NC), U4.11 (GND), U4.15 (PGND), U5.12 (AG), U5.13 (AG), U5.14 (PG), U5.15 (PG), U5.16 (PG), U6.3 (GND), U7.1 (GND), U7.15 (GND), U7.38 (GND)
EN: C8.1, C19.1, Q1.3 (C), R18.2, SW2.2, U7.3 (EN)
INFRARED: J15.4 (Black), R30.2, U7.37 (IO23)
IO0: C7.1, Q2.3 (C), SW1.2, U7.25 (IO0)
L+: J2.2, U4.1 (+OutLeft)
L-: J2.1, U4.3 (-OutLeft)
LIN: C20.1, RV2.5
Launch: Q5.3 (C), R15.1, U7.29 (IO5)
unnamed: C1.1, P1.S1 (SHIELD), R1.1
unnamed: C5.2, U2.6 (VBG)
unnamed: C6.1, J1.9 (SHIELD), R10.1
unnamed: C9.1, U5.6 (VCB)
unnamed: C9.2, L1.2, U5.1 (SW), U5.2 (SW)
unnamed: C14.1, U5.8 (SS)
unnamed: C16.2, R14.1
unnamed: C20.2, R21.1
unnamed: C21.2, R22.1
unnamed: C22.1, U4.8 (Vref)
unnamed: C29.1, R3.2, U2.7 (INA-)
unnamed: C29.2, R25.2, U2.8 (INA+)
unnamed: D5.3 (A), J6.2, Q3.2 (D), Q4.2 (D)
unnamed: D6.1 (K), L2.2, U1.2 (OUT)
unnamed: J10.1, R23.2, R24.1
unnamed: J10.2, Q5.1 (B)
unnamed: J14.2, K2.2 (COIL_1)
unnamed: Q1.1 (B), R11.1
unnamed: Q2.1 (B), R12.1
unnamed: Q6.1 (B), U2.2 (BASE)
unnamed: R14.2, U5.10 (COMP)
unnamed: R19.2, U7.35 (TXD0)
unnamed: R20.2, U7.34 (RXD0)
unnamed: R21.2, U4.7 (InLeft)
unnamed: R22.2, U4.10 (InRight)
unnamed: R26.2, R27.1, U2.4 (VFB)
Power+: J9.2, R16.2, U7.27 (IO16)
Power-: J18.2, R17.2, U7.28 (IO17)
R+: J3.2, U4.14 (-OutRight)
R-: J3.1, U4.16 (+OutRight)
RGB: J5.2, U7.12 (IO27)
RIN: C21.1, RV2.2
RTS: Q1.2 (E), R12.2, U3.14 (~RTS)
RXD: R19.1, U3.3 (RXD)
S+: R25.1, TP4.1
S-: R3.1, TP3.1
SCK: U2.11 (PD_SCK), U7.30 (IO18)
SERVO: J4.2, U7.8 (IO32)
Switch1: J7.2, J13.2, K1.1 (COM), K1.2 (COIL_1), K2.1 (COM)
Switch2: J14.1, K1.5 (N.C)
TXD: R20.1, U3.2 (TXD)
VBUS: C10.1, C13.1, D2.4 (VCC), P1.A4 (VBUS), P1.A9 (VBUS), P1.B4 (VBUS), P1.B9 (VBUS), U6.6 (VIN)

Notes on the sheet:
USB Connector
USB to TTL
Micro SD Socket
3.3V Voltage Regulators
Voltage Selector
Motor Control and Connector
Battery Connector +12V
Servo Connector
Rigth Audio Output
Left Audio Output
Audio Circuit PAM8403
Camera Connector Vcc
Display Connector Vcc
Sensor Weight Connector
5V Voltage Regulator
Volume Control
Charger Connector +12V
HX711 Module, Sensor Weight
Power Connector -
Led Launch Connector
Launch Switch Connector
Battery sensing
Switch Key Connector
Battery Connector
ESP32 WROOM Microcontroller
Sensor Switch Infrared Connector
Power Connector +
RGB Connector
BatMEs reaches when +BAT=15.3

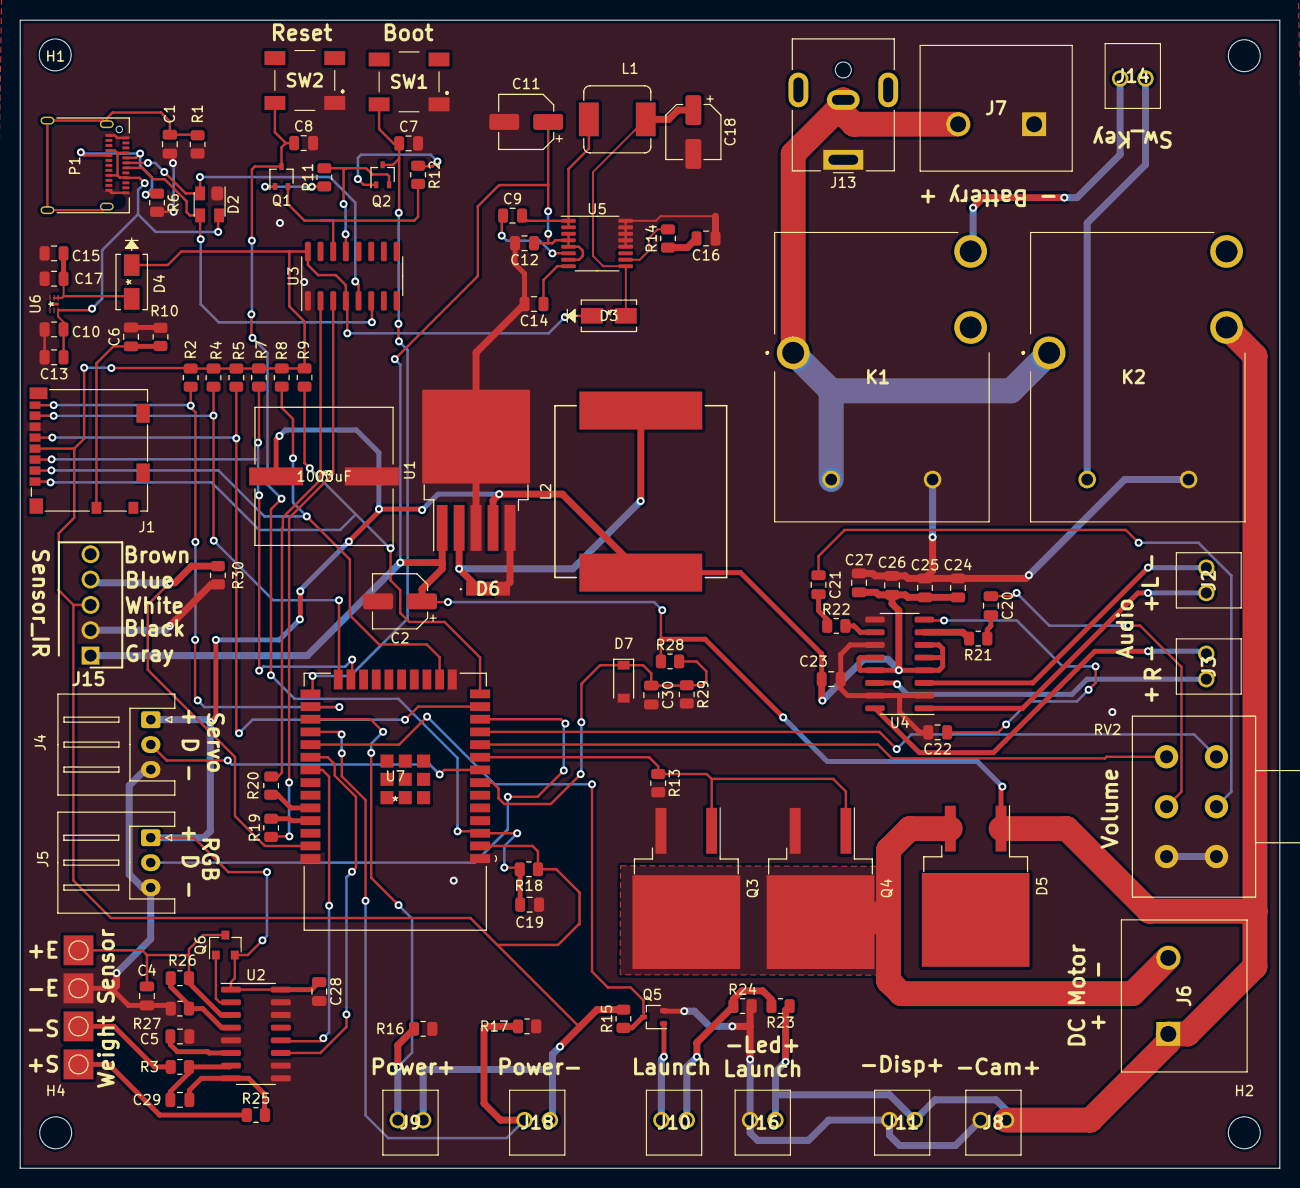
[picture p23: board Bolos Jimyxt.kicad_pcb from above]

Board: 2 copper layers, 126.2 x 115.1 mm, 111 parts (0 on the bottom side), 71 nets.

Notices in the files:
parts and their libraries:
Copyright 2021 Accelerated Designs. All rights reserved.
